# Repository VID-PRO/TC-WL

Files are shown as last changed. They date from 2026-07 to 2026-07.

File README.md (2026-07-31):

# [VID-PRO](https://www.vid-pro.de) TC-WL

Reads Panasonic GH5 timecode from HDMI via TC358743 and regenerates it as SMPTE-12M LTC audio. Three PlatformIO environments: **TC-WL-HDMI** (Waveshare ESP32-P4-WIFI6, HDMI receiver, BLE server), **TC-WL-LTC** (Seeed Studio XIAO ESP32-C3, dual-role: BLE server with LTC input or BLE client with LTC output), and **TC-WL-CLAP** (ESP32-C3, BLE client, LED matrix + OLED). TC-WL-HDMI has no LED matrix — it uses a different GPIO layout from the LTC/CLAP boards.

---

## Features

| Category | Details |
|---|---|
| **HDMI timecode capture** | Decodes GH5 timecode from HDMI Vendor-Specific InfoFrame via TC358743 I2C — no video decoding needed |
| **LTC generation** | Standalone SMPTE-12M biphase-mark encoder, esp_timer-driven, independent of I2C polling |
| **Frame rates** | Auto-detected from HDMI (24/25/30/50/60 fps) or manual via web UI |
| **RTC fallback** | HDMI uses ESP32-P4 internal RTC (synced by HDMI timecode); LTC/CLAP use optional external DS3231 — both with frame interpolation |
| **LED matrix (CLAP)** | 8 daisy-chained MAX7219 8×8 modules (64×8 px), software SPI; runtime toggle in web UI; not available on HDMI or LTC (GPIO conflict with buttons) |
| **OLED display (optional)** | 128×64 SSD1306 on shared I2C bus: device name, battery gauge + runtime, big timecode, 5 bottom boxes (MASTER/SLAVE, lock state, A/M, fps, LTC mode) — controlled via 4 physical buttons on HDMI/LTC/CLAP |
| **Web UI** | Fullscreen dark-teal SPA: timecode display, Auto/fixed FPS config, jam sync, brightness slider, matrix on/off, WiFi config |
| **WiFi** | AP on boot; auto-STA connect to saved network; AP re-enables on disconnect |
| **Reverse-engineer mode** | Dumps InfoFrame packets over serial to find GH5's exact timecode byte layout |
| **BLE wireless sync** | HDMI advertises timecode via BLE notify; LTC/CLAP scan by service UUID, subscribe to notifications, run local LTC + display |
| **BLE config** | Android app sends config commands (FPS, brightness, jam, mode, name, restart, scan, select, disconnect_master) over BLE config characteristic `9a6f0004` — no WiFi needed |

---

## Hardware

### Bill of Materials

#### TC-WL-HDMI (Waveshare ESP32-P4-WIFI6)
| Component | Notes | Buy |
|---|---|-----|
| **Waveshare ESP32-P4-WIFI6** | ESP32-P4 + ESP32-C6 companion for WiFi/BLE | [waveshare.com](https://www.waveshare.com) |
| **TC358743 HDMI→CSI-2** | e.g. Geekworm C790 — I2C + CSI-2 | widely available |
| **22-pin to 15-pin CSI ribbon cable** | Connects TC358743 to ESP32-P4-WIFI6 CSI connector | search "22-pin to 15-pin CSI cable" |
| **128×64 OLED SSD1306 (optional)** | I2C, shares bus with TC358743 | any electronics supplier |
| **3.5mm TRS jack** | LTC audio output | any electronics supplier |
| **R1: 1kΩ, C1: 4.7nF, C2: 1µF** | LTC low-pass + DC block | — |
| **R3, R4: 10kΩ** | LTC level pad | — |
#### TC-WL-LTC (Seeed Studio XIAO ESP32-C3)

| Component | Notes |
|---|---|
| **Seeed Studio XIAO ESP32-C3** | 400 MHz RISC-V, USB-C |
| **MAX7219 8×8 LED matrix** | 8 daisy-chained modules (64×8 px) |
| **DS3231 RTC (optional)** | I2C |
| **128×64 OLED SSD1306 (optional)** | I2C |
| **3.5mm TRS jack** | LTC audio in/output |
| **Passives** | Same RC filter as HDMI board |

### Pinout

| Function | TC-WL-HDMI (ESP32-P4) | TC-WL-LTC (ESP32-C3) | TC-WL-CLAP (ESP32-C3) |
|---|---|---|---|
| **I2C SDA** | GPIO 7 | GPIO 4 | GPIO 4 |
| **I2C SCL** | GPIO 8 | GPIO 5 | GPIO 5 |
| **I2C devices** | TC358743 `0x0F`, OLED `0x3C` | OLED `0x3C`, DS3231 `0x68` | OLED `0x3C` |
| **MAX7219 DIN** | — | — | GPIO 2 |
| **MAX7219 CS** | — | — | GPIO 3 |
| **MAX7219 CLK** | — | — | GPIO 10 |
| **LTC output** | GPIO 6 | GPIO 6 | GPIO 6 |
| **LTC input (master)** | — | GPIO 7 | — |
| **Battery ADC (LiPo)** | GPIO 20 (ADC1_CH4)² | GPIO 0 (A0) | GPIO 0 (A0) |
| **Button UP** | GPIO 27 | GPIO 8 | GPIO 1 |
| **Button DOWN** | GPIO 32 | GPIO 9 | GPIO 7 |
| **Button OK** | GPIO 33 | GPIO 2 | GPIO 8 |
| **Button CANCEL** | GPIO 46 | GPIO 3 | GPIO 9 |
| **TC358743 reset** | GPIO 4 (CSI CE pin) | — | — |
| **CSI connector** | 22-pin to TC358743 | — | — |

> ² Also available: GPIO 21 (ADC1_CH5, pin 11), GPIO 22 (ADC1_CH6, pin 7), GPIO 23 (ADC1_CH7, pin 8). All on 40-pin header, no conflicts with I2C/buttons/LTC/reset/CSI.

---

## Software

### Environments

| Env | Board | Role | BLE | Platform |
|-----|---|---|-----|---|
| `TC-WL-LTC` | Seeed Studio XIAO ESP32-C3 | Dual-role: master (BLE server + LTC input) or slave (BLE client + LTC output), OLED + RTC, physical buttons, OLED menu; MAX7219 matrix not supported (GPIO conflict with buttons) | ✓ (native C3) | `pioarduino/platform-espressif32`† |
| `TC-WL-CLAP` | ESP32-C3 Super Mini | BLE client, LED matrix + OLED, physical buttons + OLED menu | ✓ (native C3) | `pioarduino/platform-espressif32`† |
| `TC-WL-HDMI` | ESP32-P4-WIFI6 | HDMI receiver, BLE server (multi-connection), physical buttons + OLED menu | via C6 coprocessor‡ (ESP-Hosted SDIO) | `pioarduino/platform-espressif32`† |

† Pinned to GitHub: `https://github.com/pioarduino/platform-espressif32.git` (needed for ESP32-P4 `esp_timer` API compatibility; also used by LTC/CLAP for consistency)
‡ ESP32-P4 has no native BLE controller. The Waveshare board's ESP32-C6 companion provides WiFi/BLE over SDIO via ESP-Hosted firmware (pre-flashed). On cold power-on the C6 may take 8-12s to boot; the P4 prints a countdown, then calls `BLEDevice::init()` which blocks on ESP-Hosted SDIO enumeration until the C6 responds. All BLE code uses preprocessor guards (`SOC_BLE_SUPPORTED \|\| CONFIG_ESP_HOSTED_ENABLE_BT_NIMBLE`) to compile correctly on P4.

> **⚠️ NimBLE `reset()` bug**: The Arduino BLE library's NimBLE `reset()` omitted `m_advParams.channel_map` (defaulted to 0 = no advertising channels). This caused the C6 to never transmit ADV_IND frames — the device was connectable via direct CONNECT_IND (LTC worked) but invisible to BLE scanners. Fixed by patching the installed library at `BLEAdvertising.cpp:1459` to set `channel_map = 0x07`. A second fix restarts advertising after each connection so the Android app can discover the HDMI even while the LTC is connected.

### Building

```bash
# LTC (ESP32-C3, full I/O)
pio run -e TC-WL-LTC -t upload

# CLAP (ESP32-C3, LED matrix only)
pio run -e TC-WL-CLAP -t upload

# HDMI (ESP32-P4-WIFI6)
pio run -e TC-WL-HDMI -t upload
```

Monitor:
```bash
pio device monitor -b 115200
```

### Project Layout

```
platformio.ini
src/config.h                   pin assignments, feature toggles, battery runtime default (common base)
src/config_tcwl_ltc.h             -include for TC-WL-LTC env
src/config_tcwl_clap.h            -include for TC-WL-CLAP env
src/config_tcwl_hdmi.h            -include for TC-WL-HDMI env
src/main.cpp                   compile-time dispatch: TC-WL-HDMI/LTC/CLAP paths
src/webui/                     WiFi AP/STA, HTTP server, NVS, embedded JS/CSS/HTML
src/hdmi/                      TC358743 I2C driver + register map + GH5 timecode decoder
src/ltc/                       esp_timer-based SMPTE-12M LTC generator
src/matrix/                    MAX7219 64×8 framebuffer driver (CLAP only)
src/oled/                      optional SSD1306 via U8g2
src/rtc/                       DS3231 (external) or InternalRtc (ESP32-P4 POSIX time) RTC driver
src/timecode/                  BLE HDMI (advertise/notify) & LTC (scan/select/connect/subscribe)
3DPrints/                     STL/3MF enclosures for TC-WL-HDMI (ESP32-P4) and TC-WL-CLAP (ESP32-C3 + LED matrix)
```

---

## WiFi

| Scenario | Behavior |
|---|---|
| No WiFi configured | Opens AP with default SSID (HDMI: `TC-WL-HDMI-XXXX`, LTC: `TC-WL-LTC-XXXX`, CLAP: `TC-WL-CLAP-XXXX`), open network, `192.168.4.1` |
| Saved credentials exist | Connects as STA on boot; AP auto-disables on connect |
| STA disconnected >5 s | AP re-enabled for reconfiguration |

### Configuring WiFi

You can set WiFi credentials through the **Web UI** (open `http://192.168.4.1` in AP mode) or the **Android companion app** over BLE — no WiFi connection needed.

In the Android app's config drawer (bottom-right gear icon):

| Control | BLE Command | Description |
|---|---|---|
| **WiFi toggle** | `wifi:1` / `wifi:0` | Enables/disables the WiFi radio |
| **SSID + Password fields** | `wifi_ssid:MyNetwork,password123` | Sets and saves credentials to NVS; device connects on next reboot |
| **Save WiFi** (button) | — | Sends `wifi_ssid` with the entered `SSID,password` over BLE config characteristic |
| **Forget WiFi** (button) | `wifi_forget:1` | Clears saved SSID/password from NVS |

After saving credentials, the device stores them in NVS and reboots. On restart it connects as STA; if connection fails or the network is unavailable, the AP re-opens after 5 s for reconfiguration.

The config drawer also reads the **device state** from the BLE config characteristic. The response format is `wifi=0|1|ssid=MyNetwork|ip=192.168.1.42|rssi=-65|fw=1.5.2|conn=1|conn_name=TC-WL-HDMI-1234|scanning=0|scan_count=3|scan_name_0=DevA|scan_addr_0=aa:bb:cc:dd:ee:ff...` (pipe-separated key=value pairs), so the app always shows the actual WiFi status, SSID, IP address, signal strength, firmware version, master connection state, and scan results from the device.

---

## Web Interface

Open `http://192.168.4.1` (AP mode) or the ESP's STA IP. The header displays a centered **VID-PRO** link (https://www.vid-pro.de).

| Feature | Description |
|---|---|
| **Timecode display** | Fullscreen `dd:hh:mm:ss:ff` with color-coded status dot (green=HDMI, orange=RTC, gray=free) |
| **FPS config** | Auto (re-detect from HDMI) or fixed 24/25/30/50/60, drop-frame toggle, saved to NVS |
| **Jam sync** | Set timecode manually (dd:hh:mm:ss:ff) |
| **Brightness (LTC/CLAP)** | Slider for MAX7219 intensity (0–15), saved to NVS |
| **Matrix toggle (LTC/CLAP)** | Enable/disable LED matrix display at runtime, saved to NVS |
| **WiFi config** | SSID/password input, saved to NVS, forget option |
| **BLE (HDMI)** | Change broadcast name, view connected client count, disconnect all |
| **BLE (LTC master)** | Same server controls as HDMI (change server name, view/disconnect clients), plus LTC decoder status |
| **BLE (LTC/CLAP slave)** | Scan for HDMI or LTC-master server devices (name + address), tap to connect, view server name; lock box shows `B` (BLE synced), `R` (RTC), or `F` (free) |

---

## Configuration Defaults

| Setting | HDMI (BLE server, no matrix) | LTC (dual-role master/slave, no HDMI) | CLAP (LED matrix + OLED) |
|---|---|---|---|
| **WiFi AP SSID** | `TC-WL-HDMI-` + last 4 MAC digits | `TC-WL-LTC-` + last 4 MAC digits | `TC-WL-CLAP-` + last 4 MAC digits |
| **Battery ADC** | GPIO 20 (`BAT_ADC_PIN = 20`) | GPIO 0 (`BAT_ADC_PIN = 0`) | GPIO 0 (`BAT_ADC_PIN = 0`) |
| **Battery runtime** | `BAT_FULL_RUNTIME_MIN = 600` (10 h) | `BAT_FULL_RUNTIME_MIN = 600` (10 h) | `BAT_FULL_RUNTIME_MIN = 600` (10 h) |
| FPS | Auto (re-detect) | Auto (re-detect†) | Auto (re-detect†) |
| Drop frame | Off | Off | Off |
| RTC | Internal (ESP32-P4), no external chip needed | Optional (DS3231) | Optional (DS3231) |
| OLED | Optional (SSD1306) | Optional (SSD1306) | Optional (SSD1306) |
| MAX7219 matrix | Disabled (no hardware) | Disabled (no hardware) | Enabled by default |
| Matrix brightness | N/A | N/A | 4 |
| LTC output pin | GPIO6 | GPIO6 | GPIO6 |
| LTC input pin (master) | — | GPIO7 | — |
| Physical buttons + OLED menu | GPIO 10/9/2/3 (UP/DOWN/OK/CANCEL) | GPIO 8/9/2/3 (UP/DOWN/OK/CANCEL) | GPIO 1/7/8/9 (UP/DOWN/OK/CANCEL) |
| TC_RESET_PIN | `4` | — | — |
| Reverse-engineer mode | 0 (set to 1 in `config_tcwl_hdmi.h`) | — | — |
| BLE role | Server (advertise + notify) | Configurable: master (server + LTC input) or slave (client + LTC output) | Client (scan + subscribe) |

† Relies on HDMI frame-sync on HDMI; no-op on LTC/CLAP (falls back to configured FPS).

---

## OLED Display Layout

The 128×64 SSD1306 display is organized in three fixed zones (HDMI, LTC, and CLAP builds):

```
┌─ Top line (8×13 font) ────────────────────────┐
│ B ≡ Device Name (centered)         [||||] 10h │
│ ble  wifi                      battery runtime│
│ icon icon                                     │
├─ Timecode (logisoso18, centered) ─────────────┤
│                  88:88:88:88                  │
├─ Bottom line (6×10, 5 bordered boxes) ────────┤
│ [M] [H] [A] [25fps] [LTC-O]                   │
│  └─ role  └─ lock  └─ FPS  └─ FPS    └─ LTC   │
│              state    mode    rate      mode  │
└───────────────────────────────────────────────┘
```

* **Box 1 (68 px):** `M` (Master) or `S` (Slave)
* **Box 2 (28 px):** `H` (HDMI locked), `L` (LTC input locked), `B` (BLE synced), `R` (RTC free-run), `F` (free-run, no RTC)
* **Box 3 (28 px):** `A` (auto FPS) or `M` (manual FPS)
* **Box 4 (56 px):** Framerate — `24fps`, `25fps`, `30fps`, `50fps`, `60fps`
* **Box 5 (56 px):** LTC mode — `LTC-O` (OUT), `LTC-I` (IN), `LTC-B` (BOTH)

### OLED Menu (HDMI, LTC & CLAP)

A 4-button menu (UP/DOWN/OK/CANCEL) overlays the main screen when any button is pressed. The menu title is `SETTINGS`. Inactive for 15 s it auto-closes. Item values are right-aligned. Scroll arrows (▲/▼) are drawn with `fillTriangle()` on the right side when the list overflows.

Reboot flow: pressing OK on **Mode** or **LTC Role** shows the new value for 2 s, then a centered **REBOOT** screen for 500 ms, then `ESP.restart()`.

**LTC menu** (also used by CLAP) — each item shows a value on the right; OK cycles/toggles; long‑OK on items marked † restarts:

```
 SETTINGS
 >FPS        25
 DropFr     Off
 FPS Mode   Man
 Mode     Slave
 LTC Role    IN
 Set TC
 LTC Out     On
 WiFi        On
 OLED        On
 Matrix     Off
 Bright       4
 Exit
```

| Item | Values | Action |
|---|---|---|
| **FPS** | 24, 25, 30, 50, 60 | Cycles FPS; saved to NVS |
| **DropFr** | On / Off | Toggles drop frame |
| **FPS Mode** | Auto / Man | Toggles between auto-detect and manual FPS |
| **Mode** | Master / Slave | Toggles BLE role; 2 s preview → reboot |
| **LTC Role** | IN / OUT / BOTH | Cycles on each OK press; automatically accepts after 2 s idle (up/down/cancel cancels pending accept); 2 s preview → reboot |
| **Set TC** | — | Opens timecode editor (DD/HH/MM/SS/FF fields); OK advances field, OK on FF jams timecode; cancel exits without saving |
| **LTC Out** | On / Off | Enables/disables LTC output |
| **WiFi** | On / Off | Toggles WiFi radio |
| **OLED** | On / Off | Toggles display |
| **Matrix** | On / Off | Toggles LED matrix display |
| **Bright** | 0–15 | Cycles MAX7219 brightness |
| **Exit** | — | Closes menu |

**HDMI menu** (subset — no LTC decoder, no matrix hardware):

```
 SETTINGS
 >FPS         25
 DropFr      Off
 FPS Mode   Auto
 Set TC
 LTC Out      On
 WiFi         On
 OLED         On
 Exit
```

| Item | Values | Action |
|---|---|---|
| **FPS** | 24, 25, 30, 50, 60 | Cycles FPS |
| **DropFr** | On / Off | Toggles drop frame |
| **FPS Mode** | Auto / Man | Toggles between auto-detect and manual FPS |
| **Set TC** | — | Opens timecode editor — jam is a no-op (no LTC encoder in HDMI role); exit cancels |
| **LTC Out** | On / Off | Enables/disables LTC output |
| **WiFi** | On / Off | Toggles WiFi radio |
| **OLED** | On / Off | Toggles display |
| **Exit** | — | Closes menu |

## Battery Monitoring

All three variants support single-cell LiPo monitoring via a voltage divider on the ADC pin:
- **TC-WL-HDMI:** GPIO 20 (ADC1_CH4)
- **TC-WL-LTC:** GPIO 0 (A0)
- **TC-WL-CLAP:** GPIO 0 (A0)

The ADC (12-bit, 11 dB attenuation) is read every 10 s; voltage is converted to 0–100 % over the 3.3–4.2 V range using `BAT_DIVIDER` (default 2.0 f for a 200k:200k divider). Remaining runtime is estimated from `batteryPct × BAT_FULL_RUNTIME_MIN / 100` and displayed as `Xh` (≥1 h) or `Xm` (<1 h) right of the battery icon. Set `BAT_FULL_RUNTIME_MIN` in config to match your battery and load.

## BLE Wireless Sync

A custom 128-bit BLE service (`9a6f0001-...`) transfers timecode from HDMI/LTC to LTC/CLAP as 9-byte notifications:

### Characteristics

| UUID | Name | Properties | Description |
|---|---|---|---|
| `9a6f0002` | Timecode | READ + NOTIFY | 9-byte packet: dd, hh, mm, ss, ff, lockState, fps, flags, batteryPct |
| `9a6f0003` | Name | WRITE | Peer announces its display name |
| `9a6f0004` | Config | WRITE + READ | Write ASCII `cmd:value`; read returns pipe-delimited `key=value` state (wifi, ssid, ip, rssi, fw, conn, conn_name, scanning, scan_count, scan_name_N, scan_addr_N) |

Timecode notification bytes:

| Offset | Field | Description |
|---|---|---|
| 0 | dd | Days (0–99 BCD) |
| 1 | hh | Hours (0–23 BCD) |
| 2 | mm | Minutes (0–59 BCD) |
| 3 | ss | Seconds (0–59 BCD) |
| 4 | ff | Frames (0–59 BCD) |
| 5 | lockState | 0=Free, 1=HDMI/LTC locked, 2=RTC, 3=BLE synced |
| 6 | fps | Frame rate (24, 25, 30, 50, 60) |
| 7 | flags | Bit0=autoFps, Bit1=isMaster, Bits2-3=LTC mode (0=OUT,1=IN,2=BOTH) |
| 8 | batteryPct | Battery percentage (0–100) |

- **HDMI**: advertises the service, sends a notification on every frame tick via `bleTimecodeUpdate()`. Broadcast name configurable via web UI; disconnect button removes all connected clients. Supports multiple simultaneous BLE connections (e.g. LTC + Android app). Advertising restarts after each connection — the device remains discoverable while connected.
- **TC-WL-LTC (master)**: same BLE server role as HDMI — receives LTC audio via GPIO 7 decoder, advertises timecode over BLE. No HDMI hardware needed; can act as a standalone LTC-to-BLE bridge for slave units.
- **LTC (slave)**: scans for devices offering the service, connects, receives timecode. Also advertises its own BLE server with the config characteristic (`9a6f0004`) — the Android app can connect and send config commands (FPS, jam, mode, brightness, master scan/select/disconnect, etc.) even while the slave is synced to a master. OLED shows a 'B' icon in the top line when the Android app is connected.
- **CLAP**: BLE client only for timecode (scans, connects, subscribes to notifications), but like the LTC slave it also advertises its own BLE server with the config characteristic (`9a6f0004`) so the Android app can connect and configure it.

Server-side notifications (HDMI master, LTC master, and LTC/CLAP to the Android app) are sent at frame rate only — `bleTimecodeUpdate()` is throttled to when the timecode actually advances. Calling it on every loop iteration floods the NimBLE host and exhausts its mbuf pool, producing `ble_gatts_notify_custom: rc=6` (BLE_HS_ENOMEM).

LTC hardware runs its own LTC generator, MAX7219 matrix, OLED, web UI, and physical buttons with on-device menu. In master mode it decodes LTC from GPIO 7 and acts as a BLE timecode server; in slave mode it receives timecode via BLE and generates standalone LTC output. CLAP is client-only (no LTC input/output) with LED matrix, OLED, and a physical-button OLED menu (GPIO 1/7/8/9). On boot the CLAP initializes the matrix first, applies the saved brightness, clears it, and shows a `TC-WL-CLAP` splash while the rest of the system boots. The HDMI board has no MAX7219 hardware and uses the OLED for status display plus a menu system controlled by four physical buttons.

---

## Step 1: Reverse-engineer GH5 timecode bytes

Set `REVERSE_ENGINEER_MODE 1` in `src/config_tcwl_hdmi.h`. Connect the GH5 via HDMI, open serial monitor. The firmware scans all 256 CEA-861 packet types and dumps non-zero ACP FIFO data. The GH5's timecode is embedded in the Vendor-Specific InfoFrame (type `0x81`) accessible via the ACP packet FIFO (`TYP_ACP_SET` register), NOT via the standard `PK_VS` registers (which read zero on some modules).

**Confirmed byte layout** (ACP buffer at `PK_ACP_0HEAD` = `0x8790`, 31 bytes):

| ACP offset | Contents | GH5 TC field |
|---|---|---|
| 0 | `0x81` — VSIF header | — |
| 1 | Version (`0x01`) | — |
| 2 | Length (`0x0E`) | — |
| 3 | Rolling counter | — |
| 4–5 | Panasonic OUI (`0xF0F9…`) | — |
| 6–9 | VSIF payload (fixed) | — |
| **10** | **BCD** | **Frames (0–24 @ 25fps)** |
| **11** | **BCD** | **Seconds (0–59)** |
| **12** | **BCD** | **Minutes (0–59)** |
| **13** | **BCD** | **Hours (0–23, or 1–7 for day-of-week)** |

Fill in `decodeGh5Timecode()` in `src/hdmi/panasonic_tc.h` using these offsets, then set `REVERSE_ENGINEER_MODE 0`.

When no HDMI source is detected the system free-runs, generating LTC from the internal RTC (ESP32-P4 on HDMI) or external DS3231 (LTC/CLAP) if present, otherwise from its internal timer. It auto-switches between HDMI and free-run as sources are connected/disconnected.

---

## Time source fallback

1. **HDMI timecode** — directly drives LTC, syncs RTC once per second
2. **RTC** — ESP32-P4 internal RTC (HDMI) or DS3231 (LTC/CLAP); HH:MM:SS with sub-second frame interpolation via `millis()`
3. **Free-running tick** — advances from jam time (01:00:00:00)

---

## ⚠️ GH5 HDMI output mode

The TC358743 only supports HDMI 1.4 up to 1080p. Set the GH5's "HDMI Rec Output" to **FHD (1080p)** in the camera menu — this project only reads InfoFrame metadata, not pixel data. The GH5 may output at a non-standard resolution/TMDS rate if configured incorrectly.

## Timing: HPD → PHY config

The TC358743 PLL requires the source's TMDS clock to be present before the PHY is configured. On init, HPD is asserted high, then the code waits up to 1 s for spontaneous TMDS detection (20 × 50 ms polling `SYS_STATUS`). If TMDS appears during this window, PHY register values are applied *without* toggling `PHY_EN` (which would break the lock). If no TMDS is detected, the PHY is fully configured (disable → set registers → re-enable) and a second 1 s detection loop runs, with an HPD-retry cycle on failure. The 27 MHz reference clock override (`TC_REFCLK_HZ`) and kernel-matching PHY register values (`PHY_CTL1=0x80`, `PHY_CTL2=0x07`, `PHY_BIAS=0x40`, `PHY_CSQ=0x0A`, `AVM_CTL=45`) are applied in both paths.

## Troubleshooting TC358743

**CHIPID reads 0x0000** — the chip responds to I2C but doesn't identify as a genuine TC358743 (expected `0x44XX`). Many breakout boards sold on AliExpress/Amazon are counterfeits or damaged. Known clone quirks (confirmed on the C790 variant with CHIPID=0x0000):
- `SYS_STATUS` bit 1 (TMDS clock) reads 0 even when PLL is locked and HDMI is active — use bits 2 (PLL) + 3 (HDMI) for signal detection instead
- `FREQ_MON` always returns `0xFFFF` (measurement never completes)
- `SYSCTL` bit 4 (CK_EN) is read-only (writing `0x0010` reads back `0x0000`)
- `PK_VS` registers (`0x8770–0x878E`) return zero — read VSIF via ACP FIFO (`TYP_ACP_SET` = `0x81`, `PK_ACP_0HEAD` = `0x8790`) instead
- **PHY_EN toggle without TMDS permanently breaks detection** — enabling the PHY (`PHY_EN=1`) when no TMDS clock is present puts the PLL in a state where it can never re-lock, even after PHY `disable→re-enable`. The fix: keep PHY disabled, toggle HPD so the source starts transmitting, *then* enable PHY (TMDS already present). See [Hotplug](#hotplug-hdmi-connected-after-boot).

**Test with a known-good HDMI source** (laptop, PC) before blaming the GH5. If both produce `TMDS=0`, the TC358743 breakout board is the problem, not the camera.

**WebUI JS crashes on CLAP** — if the config drawer shows `—` for BLE status and the name input stays empty, the browser may be loading a cached version of the page from before the JS `typeof` guard fix. Hard-refresh (Cmd+Shift+R) to load the updated script. The issue was a `ReferenceError` on `oledToggle`/`ltcToggle` (excluded by `#ifndef TCWL_CLAP`) that propagated out of an IIFE and halted the entire `<script>` block before `pollBleLtc()` could register.

## ⚠️ MAX7219 Boot Glitch (CLAP)

The LED matrix may show **all LEDs on** briefly at power-on, especially on low‑power USB ports. This is a hardware limitation, not a firmware bug:

- **Root cause:** ESP32-C3 GPIO 2 (MAX7219 DIN) is a strapping pin pulled HIGH during boot. GPIO 3 (MAX7219 CS) is undefined during the ~100 ms boot‑ROM/bootloader phase. If CS floats LOW, the MAX7219 latches whatever is on DIN (HIGH → all LEDs on).
- **Slow USB ports** (e.g., MacBook) have a gradual voltage ramp that delays the ESP32-C3's startup, widening the window where CS is undefined.
- **Firmware** already drives CS=HIGH, DIN=LOW, CLK=LOW at the earliest possible point (top of `setup()` and again in `Max7219Display::begin()`), but cannot cover the boot‑ROM phase.

**Hardware fix — add a 10 kΩ pull‑up resistor:**

CLAP CS Fix

This holds CS HIGH from the moment power is applied, preventing the MAX7219 from latching any data during boot. A 4.7 kΩ resistor also works. The fix applies to all builds using the MAX7219 matrix (CLAP).

## Hotplug: HDMI connected after boot

If the system boots without HDMI and then a source is plugged in, the TC358743 hotplug detection follows a two-step fallback:

1. **HPD toggle** (fast, runs every 10 s): Pulls HPD low for 200 ms, then high for 2 s, then checks `SYS_STATUS`. No `PHY_EN` change — the clone PHY cannot recover after being enabled without TMDS, so we avoid toggling it.
2. **Chip reset + re-init** (slow, runs once during first-time acquisition only): If `SYS_STATUS` still shows no signal and we've *never* successfully locked (`!everLocked`), toggle `TC_RESET_PIN` (GPIO 4) and re-run `tc.begin()`. This replicates the boot-time sequence where TMDS is present before PHY config.

Once HDMI has been acquired at least once (`everLocked=true`), subsequent disconnects only do step 1 (HPD toggle). The LTC free‑runs without chip‑reset disruption.

**EDID**: Written to SRAM during `begin()`. The source reads it via DDC once HPD goes high. No re‑write needed on hotplug.

---

## Schematics

### LTC Output

This circuit is designed to take the digital 3.3V LTC signal from GPIO6 and filter it. The combination of R1, C1, and C2 forms a low-pass filter with DC blocking, outputting an audio-level signal (~1Vpp) compatible with professional audio inputs.

LTC Output

### LTC Input (TC-WL-LTC master mode)

This circuit is an active pre-amplifier using a single BC547 NPN transistor. It accepts a standard ±1Vpp audio-level LTC signal (from a professional generator), blocks the DC component using C3, and uses the transistor to amplify and clip the signal into a clean 0V to 3.3V logic square wave. This level-shifted signal is safe for and easily read by GPIO7 on the ESP32-C3.

LTC Input

| Part | Value | Purpose |
|---|---|---|
| C3 | 10 µF electrolytic | DC block — removes bias from incoming audio |
| R5 | 10 kΩ | Pull-up to 3.3 V (holds GPIO high when transistor off) |
| R6 | 100 kΩ | Base pulldown (keeps transistor off with no signal) |
| Q1 | BC547 (NPN) | Switches on positive half-cycles of LTC signal |

**Signal path:** Audio from TRS TIP passes through C3 to the base of Q1.
When the input rises above ≈0.7 V, Q1 turns on, pulling GPIO 7 low.
When below threshold, Q1 turns off, and R5 pulls GPIO 7 high.
The circuit inverts and clips the LTC signal — the biphase-mark transitions
are preserved and the ESP32-C3 ISR triggers on both edges, so polarity does
not matter.

For a simpler (but less robust) test, a direct connection may work if the
LTC source swings rail-to-rail (0–3.3 V).  Most professional LTC outputs
are 1 Vpp and *require* the amplifier above.

---

## Android Companion App

The `android/` directory contains a Kotlin Compose app that connects to TC-WL devices over BLE.

### Features

| Feature | Description |
|---|---|
| **OLED-like display** | Header bar (BLE icon, device name, battery + runtime), big timecode, 5 bottom boxes (role, lock state, FPS mode, fps rate, LTC mode) |
| **BLE connection** | Scan, tap to connect, auto-reconnect; shows "TC-WL" header when disconnected |
| **FPS config** | 24/25/30/50/60, drop-frame toggle — sent over BLE config characteristic |
| **Jam timecode** | Set dd:hh:mm:ss:ff via BLE |
| **Device mode (LTC)** | Switch between master and slave mode over BLE (device restarts) |
| **Brightness (CLAP)** | Slider for MAX7219 matrix intensity (0–15), only visible when connected to CLAP |
| **Device name** | Change BLE broadcast name |
| **Restart** | Remote reboot |
| **Master scan/select** | Scan for nearby master devices, tap to connect; disconnect current master; shows master name and connection status |
| **Device state** | On connect and after each config command, reads WiFi status/SSID/IP/RSSI/FW version/connection state/scan results from the Config characteristic — all fields reflect actual device state |
| **Timecode display** | Shows `--:--:--:--` when disconnected (ignoring empty BLE notifications); battery/runtime/bottom boxes show dashes when disconnected |
| **App version** | Displays app version (from `src/config.h` `FW_VERSION`) and firmware version from device state |

Config commands are sent over BLE characteristic `9a6f0004` as ASCII `cmd:value` strings — no WiFi connection required once BLE is paired. The firmware parses the commands and applies them (same logic as the HTTP API).

### Building

**Prerequisites:** JDK 17, Android SDK (set `ANDROID_HOME` or `local.properties`).

```bash
# Generate Gradle wrapper (first time only)
cd android && gradle wrapper && cd ..

# Build release APK (requires JDK 17)
export JAVA_HOME=/usr/local/opt/openjdk@17
pio run -t build_android
```

The signed release APK is at `android/app/build/outputs/apk/release/TC-WL.apk`. The build reads `FW_VERSION` from `src/config.h` and passes it to Gradle via `-PfwVersion` so the app displays its version as `"App v1.5.2"` (matching the firmware version).

### Generated files (`.gitignore`)

The Gradle build creates several generated files. These are already in `.gitignore`:

| Path | Reason |
|---|---|
| `android/app/build/` | Compiled APK, intermediates, R classes |
| `android/.gradle/` | Gradle cache and daemon files |
| `android/local.properties` | SDK path (machine-specific) |
| `android/gradlew` / `gradlew.bat` | Wrapper scripts (generated) |
| `android/gradle/wrapper/gradle-wrapper.jar` | Wrapper binary |
| `android/gradle/libs/` | Downloaded distribution archives |

The wrapper properties file (`gradle-wrapper.properties`) is kept tracked to pin the Gradle version.

### GitHub Actions

The `android.yml` workflow builds the APK on every push/PR that touches `android/`. The APK is uploaded as a workflow artifact — download from the Actions tab.

When a GitHub Release is published, the workflow also uploads `TC-WL.apk` to the release assets alongside the firmware binaries (`TC-WL-{HDMI,LTC,CLAP}_{firmware,bootloader,partitions}.bin`) built by `build-firmware.yml`. The release notes include flash instructions with the correct artifact filenames.

---

## Credits & References

- TC358743 register map: Linux kernel driver (`tc358743.c`)
- Geekworm C790: https://geekworm.com
- [MD_MAX72XX](https://github.com/MajicDesigns/MD_MAX72XX) LED matrix library
- LTC / SMPTE-12M: standard biphase-mark encoding
- [Waveshare ESP32-P4-WIFI6](https://www.waveshare.com/esp32-p4-wifi6.htm)
- [pioarduino/platform-espressif32](https://github.com/pioarduino/platform-espressif32) — community PlatformIO fork with ESP32-P4 support

---

## License

Provided as-is for personal and educational use. Panasonic and GH5 are trademarks of Panasonic Corporation.

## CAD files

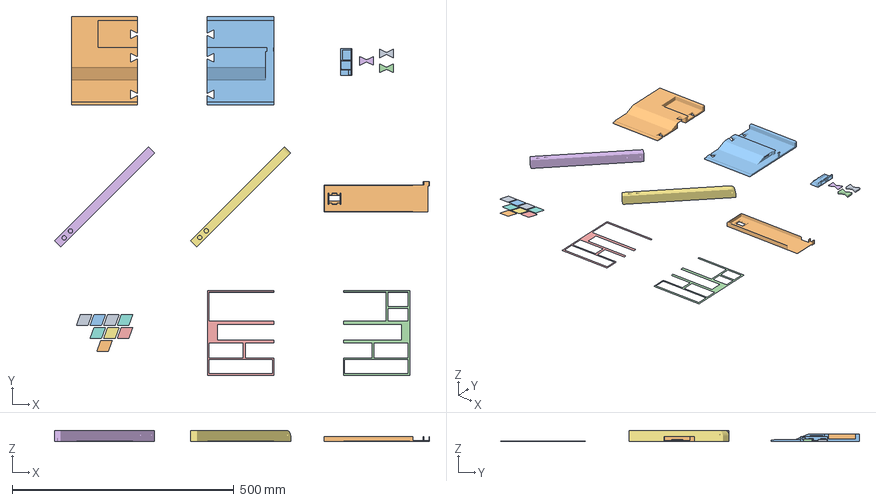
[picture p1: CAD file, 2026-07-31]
3DPrints/TC-WL-CLAP.3mf
846.7 x 810.4 x 25.0 mm
TimeCode Clap.stl_1
TimeCode Clap-3.stl x 3
TimeCode Clap.stl_A
TimeCode Clap.stl_B
TimeCode Clap-6.stl
TimeCode Clap-5.stl
TimeCode Clap-4.stl x 8
TimeCode Clap.stl_2
TimeCode Clap.stl_4
TimeCode Clap.stl_5

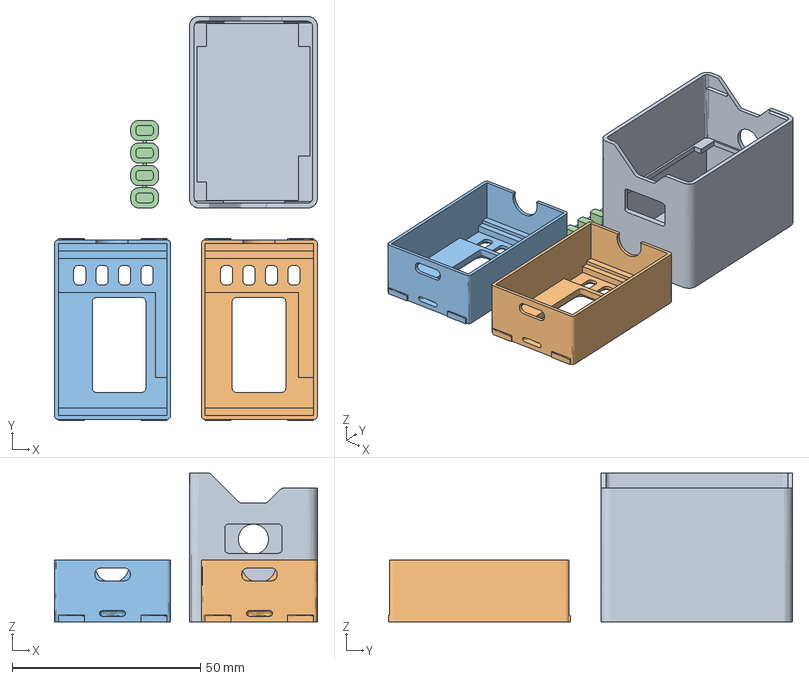
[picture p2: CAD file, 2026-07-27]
3DPrints/TC-WL-LTC.3mf
69.8 x 107.2 x 39.5 mm
TC-WL-LTC-compact-5.stl
TC-WL-LTC-compact.stl
TC-WL-LTC-compact-4.stl
TC-WL-LTC-compact-3.stl

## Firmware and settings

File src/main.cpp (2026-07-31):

#include <Arduino.h>
#include <WiFi.h>
#include <esp_wifi.h>
#include "esp_system.h"
#include "esp_sleep.h"
#include "driver/gpio.h"
#include <Preferences.h>
#include <esp_efuse.h>
#include <esp_mac.h>
#include "config.h"
#include "hdmi/tc358743.h"
#include "hdmi/tc358743_regs.h"
#include "ltc/ltc_encoder.h"
#include "ltc/ltc_decoder.h"
#include "hdmi/panasonic_tc.h"
#if RTC_ENABLE
#if defined(TCWL_USE_INTERNAL_RTC)
#include "rtc/internal_rtc.h"
#else
#include "rtc/ds3231.h"
#endif
#endif
#if OLED_ENABLE
#include "oled/oled_display.h"
#endif
#if MAX7219_ENABLE
#include "matrix/max7219_display.h"
#endif
#if WEBUI_ENABLE
#include "webui/webui.h"
#endif
#include "timecode/ble_timecode.h"

#if OLED_ENABLE
#include "btn/button.h"
#include "oled/oled_menu.h"
#endif

// ---------------------------------------------------------------------------
// Master-specific globals
// ---------------------------------------------------------------------------
#if TCWL_HDMI
TC358743 tc(Wire, TC_I2C_ADDR);
#endif
LtcEncoder ltc(LTC_OUT_PIN, LTC_FPS, LTC_DROP_FRAME);
#if TCWL_LTC
static LtcDecoder ltcDecoder(LTC_IN_PIN);
#endif
static char tcStr[13] = "00:00:00:00";

// Master role sub-modes — stored in NVS ("ltc" namespace, key "m_role")
#define MASTER_ROLE_IN   0   // decode LTC input only, no output
#define MASTER_ROLE_OUT  1   // generate LTC output only, free-running
#define MASTER_ROLE_BOTH 2   // decode input AND generate output

static int getMasterRole() {
    Preferences p;
    p.begin("ltc", false);
    int role = p.getUChar("m_role", MASTER_ROLE_IN);
    p.end();
    return role;
}

static void setMasterRole(int role) {
    Preferences p;
    p.begin("ltc", false);
    p.putUChar("m_role", (uint8_t)role);
    p.end();
}

static const char* masterRoleStr(int role) {
    switch (role) {
        case MASTER_ROLE_IN:   return "IN";
        case MASTER_ROLE_OUT:  return "OUT";
        case MASTER_ROLE_BOTH: return "BOTH";
        default:               return "?";
    }
}

static void fmtTcStr(uint8_t hh, uint8_t mm, uint8_t ss, uint8_t ff) {
    snprintf(tcStr, sizeof(tcStr), "%02u:%02u:%02u:%02u", hh, mm, ss, ff);
}

#if OLED_ENABLE
static OledDisplay oled;
static char gDeviceName[33] = "";

static bool _pendingReboot = false;
static unsigned long _rebootTimer = 0;

static bool _delayedRecycle = false;
static unsigned long _lastRecycle = 0;

enum TcEditField { TC_DD, TC_HH, TC_MM, TC_SS, TC_FF };
static bool _editingTc = false;
static TcEditField _editField = TC_DD;
static uint8_t _editVals[5] = {0, 0, 0, 0, 0};
static uint8_t _menuOpenBtn = 0;

// Master selection state
static bool _selectingMaster = false;
static BleScanResult _menuScanResults[16];
static uint8_t _menuScanCount = 0;
static uint8_t _menuScanCursor = 0;
static int8_t _menuScanScroll = 0;

static bool handleRebootDisplay() {
    if (!_pendingReboot) return false;
    unsigned long elapsed = millis() - _rebootTimer;
    if (elapsed >= 2000) {
        auto &d = oled.display();
        d.clearDisplay();
        d.setTextSize(2);
        d.setTextColor(WHITE);
        d.setCursor(28, 24);
        d.print("REBOOT");
        d.display();
        if (elapsed >= 2500) {
            ESP.restart();
        }
        return true;
    }
    return false;
}

static bool drawTcEditor() {
    if (!_editingTc) return false;
    auto &d = oled.display();
    d.clearDisplay();
    d.setTextSize(1);
    d.setTextColor(SSD1306_WHITE);
    const char* labels[] = {"DD", "HH", "MM", "SS", "FF"};
    d.setCursor(28, 0);
    d.print("SET TIMECODE");
    d.drawFastHLine(0, 10, 128, SSD1306_WHITE);
    int y = 17;
    for (int i = 0; i < 5; i++) {
        char buf[12];
        snprintf(buf, sizeof(buf), "%s%s: %02u", _editField == i ? ">" : " ", labels[i], _editVals[i]);
        d.setCursor(24, y);
        d.print(buf);
        y += 8;
    }
    d.drawFastHLine(0, 56, 128, SSD1306_WHITE);
    d.setCursor(14, 57);
    d.print("OK=next  CAN=exit");
    d.display();
    return true;
}

#if OLED_ENABLE && BTN_UP_PIN >= 0
static Button btnUp(BTN_UP_PIN);
static Button btnDown(BTN_DOWN_PIN);
static Button btnOk(BTN_OK_PIN);
static Button btnCancel(BTN_CANCEL_PIN);
static OledMenu menu(oled);
#endif
#endif

#if RTC_ENABLE
#if defined(TCWL_USE_INTERNAL_RTC)
static InternalRtc rtc;
#else
static DS3231 rtc(Wire, RTC_I2C_ADDR);
#endif
static bool rtcPresent = false;
static unsigned long lastRtcReadMs = 0;
static unsigned long lastRtcSyncMs = 0;
static uint8_t rtcHH = 0, rtcMM = 0, rtcSS = 0;
#endif

#if WEBUI_ENABLE
static WebUI webui;
#endif
#if MAX7219_ENABLE
static Max7219Display mx7219(MAX7219_CS_PIN, MAX7219_NUM_MODULES);
#endif

static bool tcPresent = false;
static char tcSource[8] = "FREE";

// Master fast-poll constants
static const unsigned long FAST_POLL_MS = 8;
unsigned long lastFastPoll = 0;
unsigned long lastFramePoll = 0;
unsigned long framePollMs = 1000 / LTC_FPS;

// ---------------------------------------------------------------------------
// Frame rate auto-detection (HDMI only)
// ---------------------------------------------------------------------------
#if FPS_AUTO_DETECT
static bool fpsDetected = false;
static unsigned long lastFrameUs = 0;
static unsigned long intervals[30];
static uint8_t intervalCount = 0;
static const uint8_t MIN_SAMPLES = 10;

static void resetFpsDetect() {
    fpsDetected = false;
    intervalCount = 0;
    lastFrameUs = 0;
}

static bool tryDetectFps() {
    if (intervalCount < MIN_SAMPLES) return false;

    uint32_t sum = 0;
    for (uint8_t i = 0; i < intervalCount; i++) sum += intervals[i];
    uint32_t avg = sum / intervalCount;

    uint8_t fps;
    if      (avg >= 40833) fps = 24;
    else if (avg >= 36667) fps = 25;
    else if (avg >= 26667) fps = 30;
    else if (avg >= 18333) fps = 50;
    else                   fps = 60;

    bool df = LTC_DROP_FRAME;

    if (fps != LTC_FPS || df != LTC_DROP_FRAME) {
        ltc.setFps(fps, df);
        framePollMs = 1000 / fps;
    }

    Serial.print(F("Auto-detected "));
    Serial.print(fps);
    Serial.println(F(" fps"));
    fpsDetected = true;
    return true;
}
#endif

// ---------------------------------------------------------------------------
// Reverse-engineer mode helpers (HDMI only)
// ---------------------------------------------------------------------------
#if defined(TCWL_HDMI) && REVERSE_ENGINEER_MODE
void dumpBuffer(const char *label, uint16_t reg, size_t len) {
    uint8_t buf[32];
    if (len > sizeof(buf)) len = sizeof(buf);
    tc.readBlock(reg, buf, len);
    Serial.print(label);
    Serial.print(": ");
    for (size_t i = 0; i < len; i++) {
        if (buf[i] < 0x10) Serial.print('0');
        Serial.print(buf[i], HEX);
        Serial.print(' ');
    }
    Serial.println();
}

void testEdidWrite() {
    const uint16_t TEST_REG = 0x8C00;
    Serial.println(F("--- EDID RAM test (read-only) ---"));
    Serial.print(F("EDID header: "));
    for (int i = 0; i < 8; i++) {
        Serial.print(tc.readReg8(TEST_REG + i), HEX); Serial.print(' ');
    }
    Serial.println();
}

void dumpEdid() {
    static const size_t EDID_SIZE = 256;
    uint8_t buf[EDID_SIZE];
    Serial.println(F("--- EDID readback (byte-by-byte) ---"));
    for (size_t i = 0; i < EDID_SIZE; i++) {
        buf[i] = tc.readReg8(EDID_RAM + i);
    }
    for (size_t i = 0; i < EDID_SIZE; i += 16) {
        char line[80];
        int pos = snprintf(line, sizeof(line), "%04X: ", (unsigned)i);
        for (size_t j = 0; j < 16; j++) {
            pos += snprintf(line + pos, sizeof(line) - pos, "%02X ", buf[i + j]);
        }
        Serial.println(line);
    }
    uint8_t sum0 = 0;
    for (int i = 0; i < 128; i++) sum0 += buf[i];
    Serial.print(F("Block 0 checksum: 0x")); Serial.print(sum0, HEX);
    Serial.println(sum0 == 0 ? F(" (OK)") : F(" (BAD!)"));
    uint8_t sum1 = 0;
    for (int i = 128; i < 256; i++) sum1 += buf[i];
    Serial.print(F("Block 1 checksum: 0x")); Serial.print(sum1, HEX);
    Serial.println(sum1 == 0 ? F(" (OK)") : F(" (BAD!)"));
    Serial.println();
}

void runReverseEngineerDump() {
    uint8_t st = tc.readReg8(SYS_STATUS);
    uint8_t hpd = tc.readReg8(HPD_CTL);
    uint8_t ddc = tc.readReg8(DDC_CTL);

    static bool first = true;

    // One-line status every 500ms
    Serial.print(F("SYS_STATUS: 0x")); Serial.print(st, HEX);
    Serial.print(F(" DDC5V=")); Serial.print((st >> 0) & 1);
    Serial.print(F(" TMDS="));  Serial.print((st >> 1) & 1);
    Serial.print(F(" PLL="));   Serial.print((st >> 2) & 1);
    Serial.print(F(" HDMI="));  Serial.print((st >> 3) & 1);
    Serial.print(F(" MUTE="));  Serial.print((st >> 6) & 1);
    Serial.print(F(" SYNC="));  Serial.print((st >> 7) & 1);
    Serial.print(F(" VI1=0x")); Serial.print(tc.readReg8(VI_STATUS1), HEX);
    Serial.print(F(" VI3=0x")); Serial.print(tc.readReg8(VI_STATUS3), HEX);
    Serial.println();

    // Read VSIF via ACP (type 0x81) — PK_VS registers are zero on this clone
    static uint8_t lastVsifAcp[PK_ACP_LEN] = {0};
    uint8_t vsifAcp[PK_ACP_LEN];
    tc.selectPacketType(0x81);
    delay(2);
    tc.readBlock(PK_ACP_0HEAD, vsifAcp, PK_ACP_LEN);
    bool vsifChanged = memcmp(vsifAcp, lastVsifAcp, PK_ACP_LEN) != 0;
    bool vsifNonZero = false;
    for (size_t i = 0; i < PK_ACP_LEN; i++) { if (vsifAcp[i]) { vsifNonZero = true; break; } }
    if (vsifChanged || vsifNonZero) {
        memcpy(lastVsifAcp, vsifAcp, PK_ACP_LEN);
        Serial.print(F("VSIF(ACP): "));
        for (size_t i = 0; i < PK_ACP_LEN; i++) {
            if (vsifAcp[i] < 0x10) Serial.print('0');
            Serial.print(vsifAcp[i], HEX); Serial.print(' ');
        }
        if (vsifAcp[0] == 0x81) Serial.print(F(" (VSIF)"));
        Serial.println();
    }

    if (!first) return;
    first = false;

    // Full dump once on first call
    Serial.println(F("--- full diagnostics ---"));
    // 0x85xx register write-read-back test
    uint8_t testVal = tc.readReg8(SYS_CLK);
    tc.writeReg8(SYS_CLK, 0xA5);
    uint8_t testRead = tc.readReg8(SYS_CLK);
    tc.writeReg8(SYS_CLK, testVal);
    if (testRead != 0xA5) {
        Serial.print(F("WARN: 0x85xx write/read mismatch! SYS_CLK: wrote 0xA5 got 0x"));
        Serial.println(testRead, HEX);
    }
    uint8_t vi1 = tc.readReg8(VI_STATUS1);
    uint8_t vi3 = tc.readReg8(VI_STATUS3);
    uint8_t phyCsq = tc.readReg8(PHY_CSQ);
    uint16_t sysInt = tc.readReg16(SYS_INT);
    uint8_t edidSeg = tc.readReg8(EDID_SEG);
    uint8_t edidLen1 = tc.readReg8(EDID_LEN1);
    uint8_t edidLen2 = tc.readReg8(EDID_LEN2);
    uint8_t sf0 = tc.readReg8(SYS_FREQ0);
    uint8_t sf1 = tc.readReg8(SYS_FREQ1);
    uint8_t nco = tc.readReg8(NCO_F0_MOD);
    uint8_t fhMin0 = tc.readReg8(FH_MIN0);
    uint8_t fhMin1 = tc.readReg8(FH_MIN1);
    uint8_t fhMax0 = tc.readReg8(FH_MAX0);
    uint8_t fhMax1 = tc.readReg8(FH_MAX1);
    uint8_t ldet0 = tc.readReg8(LOCKDET_REF0);
    uint8_t ldet1 = tc.readReg8(LOCKDET_REF1);
    uint8_t ldet2 = tc.readReg8(LOCKDET_REF2);
    uint8_t phyCtl0 = tc.readReg8(PHY_CTL0);
    uint16_t sysctl = tc.readReg16(SYSCTL);
    uint8_t hpdNew = tc.readReg8(0x85C8);
    uint8_t ddcNew = tc.readReg8(0x85C7);
    Serial.print(F("HPD_CTL(0x8544): 0x")); Serial.print(hpd, HEX);
    Serial.print(F(" (0x85C8): 0x")); Serial.print(hpdNew, HEX);
    Serial.print(F(" DDC_CTL(0x8543): 0x")); Serial.print(ddc, HEX);
    Serial.print(F(" (0x85C7): 0x")); Serial.print(ddcNew, HEX);
    Serial.print(F(" PHY_CSQ: 0x")); Serial.print(phyCsq, HEX);
    Serial.print(F(" VI_STAT1: 0x")); Serial.print(vi1, HEX);
    Serial.print(F(" VI_STAT3: 0x")); Serial.print(vi3, HEX);
    Serial.print(F(" SYS_INT: 0x")); Serial.print(sysInt, HEX);
    Serial.print(F(" SF:0x")); Serial.print(sf1, HEX); Serial.print(sf0, HEX);
    Serial.print(F(" FH:")); Serial.print(fhMin1, HEX); Serial.print(fhMin0, HEX);
    Serial.print(F("-")); Serial.print(fhMax1, HEX); Serial.print(fhMax0, HEX);
    Serial.print(F(" LD:")); Serial.print(ldet2, HEX); Serial.print(ldet1, HEX); Serial.print(ldet0, HEX);
    Serial.print(F(" NCO:0x")); Serial.print(nco, HEX);
    Serial.print(F(" PHYCTL0:0x")); Serial.print(phyCtl0, HEX);
    Serial.print(F(" SYSCTL:0x")); Serial.print(sysctl, HEX);
    uint8_t edidSegNum = tc.readReg8(EDID_SEG_NUM);
    Serial.print(F(" EDID_SEG: 0x")); Serial.print(edidSeg, HEX);
    Serial.print(F(" EDID_SEG_NUM: 0x")); Serial.print(edidSegNum, HEX);
    Serial.print(F(" EDID_LEN: 0x")); Serial.print(edidLen2, HEX); Serial.print(edidLen1, HEX);
    Serial.println();
    uint8_t edidHdr[16];
    for (int i = 0; i < 16; i++) edidHdr[i] = tc.readReg8(EDID_RAM + i);
    Serial.print(F("EDID_RAM[0..15]: "));
    for (int i = 0; i < 16; i++) { if (edidHdr[i] < 0x10) Serial.print('0'); Serial.print(edidHdr[i], HEX); Serial.print(' '); }
    Serial.println();
    Serial.print(F("HDMI mode: "));
    Serial.println(tc.isHdmiMode() ? F("yes (good, packets active)") : F("no (DVI - no packets!)"));

    dumpEdid();
    Serial.print(F("CEA_BLK1[0..19]: "));
    for (int i = 0; i < 20; i++) {
        uint8_t b = tc.readReg8(EDID_RAM + 128 + i);
        if (b < 0x10) Serial.print('0');
        Serial.print(b, HEX); Serial.print(' ');
    }
    Serial.println();

    dumpBuffer("AVI InfoFrame       ", PK_AVI_0HEAD, PK_AVI_LEN);
    dumpBuffer("Vendor-Specific IF  ", PK_VS_0HEAD,  PK_VS_LEN);
    dumpBuffer("Audio InfoFrame     ", PK_AUD_0HEAD, PK_AUD_LEN);
    dumpBuffer("Source Product IF   ", PK_SPD_0HEAD, PK_SPD_LEN);
    dumpBuffer("MPEG Source IF      ", PK_MS_0HEAD,  PK_MS_LEN);
    dumpBuffer("ISRC1               ", PK_ISRC1_0HEAD, PK_ISRC1_LEN);
    dumpBuffer("ISRC2               ", PK_ISRC2_0HEAD, PK_ISRC2_LEN);

    // Scan ALL CEA-861 packet types to find non-zero data (GH5 timecode location)
    Serial.println(F("--- Scanning all ACP packet types (non-zero only) ---"));
    for (uint16_t t = 0; t <= 0xFF; t++) {
        tc.selectPacketType((uint8_t)t);
        delay(2);
        uint8_t buf[PK_ACP_LEN];
        tc.readBlock(PK_ACP_0HEAD, buf, PK_ACP_LEN);
        bool allZero = true;
        for (size_t i = 0; i < PK_ACP_LEN; i++) {
            if (buf[i]) { allZero = false; break; }
        }
        if (!allZero) {
            Serial.printf("Type 0x%02X: ", t);
            for (size_t i = 0; i < PK_ACP_LEN; i++) {
                if (buf[i] < 0x10) Serial.print('0');
                Serial.print(buf[i], HEX); Serial.print(' ');
            }
            Serial.println();
        }
    }
    Serial.println(F("--- End scan ---"));

    Serial.println();
}
#endif

// ---------------------------------------------------------------------------
// Slave-specific: BLE timecode callback
// ---------------------------------------------------------------------------
static void onBleTimecode(uint8_t dd, uint8_t hh, uint8_t mm, uint8_t ss, uint8_t ff, uint8_t fps) {
    // Sync FPS from master unless the menu is active (user is changing it).
    if (!bleTimecodeIsMenuActive() && fps != ltc.fps()) {
        ltc.setFps(fps, ltc.dropFrame());
        framePollMs = 1000 / fps;
    }
    ltc.setTime(hh, mm, ss, ff);
    ltc.setDd(dd);
}

#if TCWL_LTC
static void onLtcDecoded(uint8_t dd, uint8_t hh, uint8_t mm, uint8_t ss, uint8_t ff) {
    (void)dd;
    ltc.setTime(hh, mm, ss, ff);
}

static unsigned long lastDecodedFrameMs = 0;
#endif

#if OLED_ENABLE && BTN_UP_PIN >= 0
// ── Shared OLED menu helpers ──────────────────────────────────
static void menuSaveFps(uint8_t fps, bool df) {
    ltc.setFps(fps, df);
    framePollMs = 1000 / fps;
    Preferences p;
    p.begin("ltc", false);
    p.putUChar("fps", fps);
    p.putBool("df", df);
    p.end();
}
static const char* menuGetFps() {
    static char buf[8];
    snprintf(buf, sizeof(buf), "%dfps", ltc.fps());
    return buf;
}
static void menuCycleFps() {
    static const uint8_t vals[] = {24, 25, 30, 50, 60};
    uint8_t cur = ltc.fps();
    uint8_t next = vals[0];
    for (uint8_t i = 0; i < 5; i++) {
        if (vals[i] == cur) { next = vals[(i + 1) % 5]; break; }
    }
    menuSaveFps(next, ltc.dropFrame());
}
static const char* menuGetDf() {
    return ltc.dropFrame() ? "On" : "Off";
}
static void menuToggleDf() {
    menuSaveFps(ltc.fps(), !ltc.dropFrame());
}
static const char* menuGetAutoFps() { return webui.autoFps() ? "Auto" : "Man"; }
static void menuToggleAutoFps() { webui.setAutoFps(!webui.autoFps()); }
static const char* menuGetLtcOut() { return webui.ltcEnabled() ? "On" : "Off"; }
static const char* menuGetOled()   { return webui.oledEnabled() ? "On" : "Off"; }
static const char* menuGetWifi()   { return webui.wifiEnabled() ? "On" : "Off"; }
static void menuToggleLtcOut() { webui.setLtcEnabled(!webui.ltcEnabled()); }
static void menuToggleOled()   { webui.setOledEnabled(!webui.oledEnabled()); oled.forceRedraw(); }
static void menuToggleWifi()   { webui.setWifiEnabled(!webui.wifiEnabled()); }
static void menuExit()         { menu.hide(); oled.forceRedraw(); }
static void menuRestart()      { menu.hide(); _pendingReboot = true; _rebootTimer = millis(); }

// Sleep: power everything off. LTC/CLAP use deep sleep (OK is an RTC/LP GPIO
// on the C3); HDMI uses light sleep since its buttons are plain MIO pins.
static void menuSleep() {
    menu.hide();
#if OLED_ENABLE
    oled.setEnabled(false);
    oled.forceRedraw();
    oled.display().clearDisplay();
    oled.display().ssd1306_command(SSD1306_DISPLAYOFF);
    oled.display().display();
#endif
#if MAX7219_ENABLE
    mx7219.clear();
#endif
#if WEBUI_ENABLE
    WiFi.disconnect(true);
    WiFi.mode(WIFI_OFF);
#endif
#if defined(BTN_OK_PIN) && BTN_OK_PIN >= 0
    pinMode(BTN_OK_PIN, INPUT_PULLUP);
    gpio_pullup_en((gpio_num_t)BTN_OK_PIN);
#endif
#if TCWL_HDMI
    gpio_wakeup_enable((gpio_num_t)BTN_OK_PIN, GPIO_INTR_LOW_LEVEL);
    esp_sleep_enable_gpio_wakeup();
    Serial.println(F("Entering light sleep..."));
    esp_light_sleep_start();
    Serial.println(F("Woke up"));
#if OLED_ENABLE
    oled.setEnabled(true);
    oled.display().ssd1306_command(SSD1306_DISPLAYON);
    oled.forceRedraw();
#endif
#if WEBUI_ENABLE
    if (webui.wifiEnabled()) webui.setWifiEnabled(true);
#endif
#else
#if SOC_GPIO_SUPPORT_DEEPSLEEP_WAKEUP
    esp_deep_sleep_enable_gpio_wakeup(1ULL << BTN_OK_PIN, ESP_GPIO_WAKEUP_GPIO_LOW);
#else
    esp_sleep_enable_ext0_wakeup((gpio_num_t)BTN_OK_PIN, 0);
#endif
    Serial.println(F("Entering deep sleep..."));
    esp_deep_sleep_start();
#endif
}

#if TCWL_LTC
// ── LTC-specific menu helpers ─────────────────────────────────
static const char* menuGetMode() {
    return bleGetMode() == TCWL_MODE_LTC_MASTER ? "Master" : "Slave";
}
static void menuToggleMode() {
    bleSetMode(bleGetMode() == TCWL_MODE_LTC_MASTER ? TCWL_MODE_LTC : TCWL_MODE_LTC_MASTER);
    menu.hide();
    _pendingReboot = true;
    _rebootTimer = millis();
}
static const char* menuGetMatrix() { return webui.matrixEnabled() ? "On" : "Off"; }
static const char* menuGetBright() {
    static char buf[4];
    snprintf(buf, sizeof(buf), "%d", webui.brightness());
    return buf;
}
static void menuToggleMatrix() { webui.setMatrixEnabled(!webui.matrixEnabled()); }
static void menuCycleBright()  { webui.setBrightness((webui.brightness() + 1) % 16); }

static const char* menuGetRole() { return masterRoleStr(getMasterRole()); }
static void menuCycleRole() {
    int r = getMasterRole();
    r = (r + 1) % 3;
    setMasterRole(r);
    _delayedRecycle = true;
    _lastRecycle = millis();
}
#endif

// ── Shared TC editor (both LTC and HDMI) ─────────────────────
static void menuSetTc() {
    menu.hide();
    _editingTc = true;
    _editField = TC_DD;
    _editVals[0] = ltc.dd();
    _editVals[1] = ltc.hh();
    _editVals[2] = ltc.mm();
    _editVals[3] = ltc.ss();
    _editVals[4] = ltc.ff();
}

static const char* menuGetMaster() {
    return bleTimecodeConnected() ? "CON" : "---";
}

static void menuSelectMaster() {
    menu.hide();
    _selectingMaster = true;
    _menuScanCount = 0;
    _menuScanCursor = 0;
    _menuScanScroll = 0;
    if (bleTimecodeConnected()) {
        // Show connected master with Disconnect option
    } else {
        bleTimecodeStartScan();
    }
    // Consume the btnOk release that triggered this callback so the
    // _selectingMaster overlay doesn't see a stale release event.
    btnOk.read();
}

static void handleTcEditorInput() {
    if (!_editingTc) return;
    if (btnUp.pressed()) {
        static const uint8_t maxVals[] = {99, 23, 59, 59, 59};
        if (_editVals[_editField] < maxVals[_editField]) _editVals[_editField]++;
    }
    if (btnDown.pressed()) {
        if (_editVals[_editField] > 0) _editVals[_editField]--;
    }
    if (btnOk.released()) {
        if (_editField >= TC_FF) {
            ltc.setTime(_editVals[1], _editVals[2], _editVals[3], _editVals[4]);
            ltc.setDd(_editVals[0]);
#if RTC_ENABLE
            if (rtcPresent) {
                rtc.setTime(_editVals[1], _editVals[2], _editVals[3]);
                rtcHH = _editVals[1]; rtcMM = _editVals[2]; rtcSS = _editVals[3];
                lastRtcSyncMs = millis();
            }
#endif
            _editingTc = false;
        } else {
            _editField = static_cast<TcEditField>(_editField + 1);
        }
    }
    if (btnCancel.released()) {
        _editingTc = false;
    }
}
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
void loop() {
#if WEBUI_ENABLE
    webui.handleClient();
#endif

#if TCWL_HDMI
    hdmiLoop();
#else
    ltcLoop();
#endif
}

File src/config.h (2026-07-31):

#pragma once

// ---------------------------------------------------------------------------
// Pin & hardware configuration — Seeed Studio XIAO ESP32-C3
// ---------------------------------------------------------------------------

// I2C pins to the TC358743 HDMI receiver board (single bus, shared with OLED & RTC)
#define TC_I2C_SDA_PIN   4
#define TC_I2C_SCL_PIN   5
#define TC_I2C_ADDR      0x0F   // default 7-bit address on most TC358743 breakout boards

// TC358743 hardware reset pin (-1 = skip, rely on internal power-on reset)
#define TC_RESET_PIN     4

// LTC audio output pin (goes to your RC filter -> 3.5mm TRS -> LTC input)
#define LTC_OUT_PIN      6

// LTC audio input pin (LTC signal from external source, TC-WL-LTC master mode only)
#define LTC_IN_PIN       7

// OLED menu push-buttons (momentary to GND, internal pull-up enabled)
// TC-WL-LTC has no LED matrix, so GPIO 2 and 3 (normally MAX7219 DIN/CS) are
// free for button use.  GPIO0/1 avoided (strapping function).
#define BTN_UP_PIN       8
#define BTN_DOWN_PIN     9
#define BTN_OK_PIN       4
#define BTN_CANCEL_PIN   5

// TC358743 RESETN has internal pull-up — no GPIO needed

// ---------------------------------------------------------------------------
// Frame rate auto-detection
// ---------------------------------------------------------------------------
#ifndef FPS_AUTO_DETECT
#define FPS_AUTO_DETECT     1
#endif

// ---------------------------------------------------------------------------
// OLED display configuration
// ---------------------------------------------------------------------------
// 128x64 SSD1306 OLED on the shared I2C bus.
#define OLED_ENABLE         1
#define OLED_I2C_ADDR       0x3C

// ---------------------------------------------------------------------------
// RTC (Real-Time Clock) configuration
// ---------------------------------------------------------------------------
// DS3231 RTC on the shared I2C bus (same SDA/SCL as TC358743 + OLED — all at
// different addresses: 0x0F, 0x3C, 0x68 — no conflict).
#define RTC_ENABLE          1
#define RTC_I2C_SDA_PIN     4   // same bus as TC358743 / OLED (only one I2C on ESP32-C3)
#define RTC_I2C_SCL_PIN     5
#define RTC_I2C_ADDR        0x68

// ---------------------------------------------------------------------------
// LTC frame rate fallback defaults
// ---------------------------------------------------------------------------
#ifndef LTC_FPS
#define LTC_FPS 25
#endif

#ifndef LTC_DROP_FRAME
#define LTC_DROP_FRAME 0
#endif

// ---------------------------------------------------------------------------
#ifndef MATRIX_ENABLED_DEFAULT
#define MATRIX_ENABLED_DEFAULT 0
#endif

// MAX7219 8x8 LED matrix display configuration (optional — set to 0 to skip)
// 8 modules daisy-chained = 64x8 pixels. Software SPI (no hardware SPI on these pins).
// Pins: see schematic for wiring on XIAO ESP32-C3.
#define MAX7219_ENABLE       1
#define MAX7219_DIN_PIN      2
#define MAX7219_CS_PIN       3
#define MAX7219_CLK_PIN      10
#define MAX7219_NUM_MODULES  8

// ---------------------------------------------------------------------------
// Battery voltage monitoring (ADC, 1/2 resistor divider on A0)
// BAT_ADC_PIN = -1 to disable; set to ADC-capable GPIO otherwise.
// BAT_DIVIDER = voltage divider ratio (e.g. 2.0 for 200k:200k).
// ---------------------------------------------------------------------------
#ifndef BAT_ADC_PIN
#define BAT_ADC_PIN           -1
#endif
#define BAT_DIVIDER           2.0f
#ifndef BAT_FULL_RUNTIME_MIN
#define BAT_FULL_RUNTIME_MIN  600           // estimated runtime (min) at 100%
#endif

// ---------------------------------------------------------------------------
// Web UI (WiFi AP + optional STA) configuration
// ---------------------------------------------------------------------------
#define WEBUI_ENABLE        1
#define WEBUI_AP_SSID       "TC-WL-AP"
#define WEBUI_AP_PASSWORD   nullptr         // nullptr = open network

// Optional: connect to an existing WiFi network (STA mode) so the web UI
// is also reachable on your LAN.  Leave SSID empty ("") to skip STA.
#define WEBUI_STA_SSID      ""
#define WEBUI_STA_PASSWORD  ""

// ---------------------------------------------------------------------------
// Operating mode (HDMI only — see config_tcwl_hdmi.h)
// ---------------------------------------------------------------------------

// ---------------------------------------------------------------------------
// Firmware version
// ---------------------------------------------------------------------------
#define FW_VERSION "v1.5.4"
 

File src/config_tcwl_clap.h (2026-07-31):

#pragma once
#include "config.h"
#define TCWL_LTC 1
#define TCWL_CLAP 1

// TC-WL-CLAP: WiFi + BLE client + LED matrix + OLED
#undef MATRIX_ENABLED_DEFAULT
#define MATRIX_ENABLED_DEFAULT 1

// OLED on shared I2C bus (SDA=GPIO4, SCL=GPIO5 — free on CLAP)
#define OLED_ENABLE 1
#define OLED_I2C_SDA_PIN   4
#define OLED_I2C_SCL_PIN   5

// OLED menu push-buttons (momentary to GND, internal pull-up enabled)
// CLAP uses free GPIOs that don't conflict with the MAX7219 matrix (2/3/10),
// OLED I2C (4/5), battery ADC (0), or LTC out (6).
#undef BTN_UP_PIN
#undef BTN_DOWN_PIN
#undef BTN_OK_PIN
#undef BTN_CANCEL_PIN
#define BTN_UP_PIN       1
#define BTN_DOWN_PIN     7
#define BTN_OK_PIN       8
#define BTN_CANCEL_PIN   9

// Battery ADC on GPIO 0 (ADC1_CH0), 200k:200k divider, 2000mAh LiPo
#undef BAT_ADC_PIN
#define BAT_ADC_PIN           0
#undef BAT_FULL_RUNTIME_MIN
#define BAT_FULL_RUNTIME_MIN  600   // 2000mAh / ~200mA ≈ 10h

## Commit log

2026-07-24 fixed drift on slave
    [main.cpp]
2026-07-25 TC-WL-LTC 3d case
    [TC-WL-LTC.3mf]
2026-07-25 fixed minimal frame offset
    [main.cpp]
2026-07-25 fixed master selection from oled menu
    [ble_timecode.cpp]
2026-07-27 3d file tc-wl-ltc
    [TC-WL-LTC.3mf]
2026-07-31 clap startup matrix fix
    [config.h, main.cpp]
2026-07-31 fixed ble_gatts_notify_custom error, oled menu for clap
    [config_tcwl_clap.h, main.cpp]
2026-07-31 tc-wl-clap 3d
    [TC-WL-CLAP.3mf]
2026-07-31 sleep from oled menu, wakeup OK
    [TC-WL-CLAP.3mf]
2026-07-31 clap 3d
    [TC-WL-CLAP.3mf]
